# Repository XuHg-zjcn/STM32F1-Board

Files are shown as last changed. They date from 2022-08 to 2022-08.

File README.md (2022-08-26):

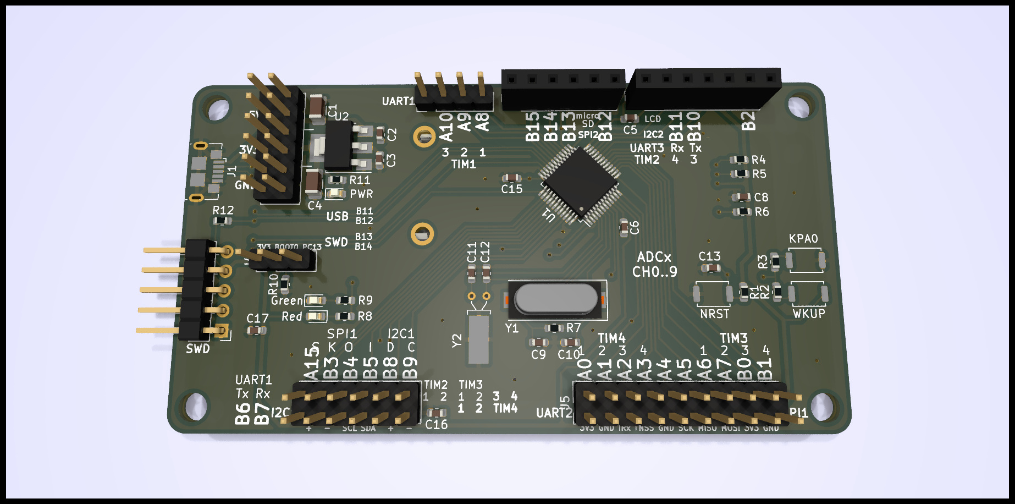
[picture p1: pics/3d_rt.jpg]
光线追踪图

# PCB描述
## 主芯片
STM32F103C8T6  LQFP48  
RAM 20kB, Flash 64kB  

## 板载元件
- 电源 : AMS1117-3.3 滤波电容47u 104
- 电池 : CR1220, 104电容
- 晶振 :  8M, 32.768K, 负载电容, 负载电阻

## 用户交互
- 按钮 : NRST, WKUP, KPA0
- LED  : 红绿双色(PC13, 一个引脚驱动两个LED)
- OLED : I2C四针插口J9

## 接口
|标识| 名称|描述 |
|:--:|:---:|:---|
| J1 |USB  |microUSB接口 |
| J2 |电源 |GND 3V3 5V 每种电压有4个针 |
| J3 |SWD  |顺序为GND SWCLK SWDIO 3V3 5V, 是为了兼容其他的板子|
| J4 |保护 |USB, SWD, BOOT0 |
| J5 |ADC  |有10个通道 |
| J6 |SPI1 |用户, 与ADC 4,5,6,7重叠 |
| J7 |UART1|用户,  并入PA8引脚 |
| J8 |I2C1 |用户 |
| J9 |I2C2 |液晶屏, 并入PB2引脚 |
|J10 |SPI2 |有保护罩, 已经连接microSD |
|J11 |SD |microSD卡槽 |

## 未来计划
配件组合:  
- 电池: CR1220 / 3.7V锂电池(二选一)
- 储存: microSD / SPI Flash(二选一), I2C EEPROM(可选)

# 本项目规范
除了引脚编号，其他单根线的标签文字统一使用0.15mm宽度，多根线统一使用0.2mm宽度文字。

电源0.29mm

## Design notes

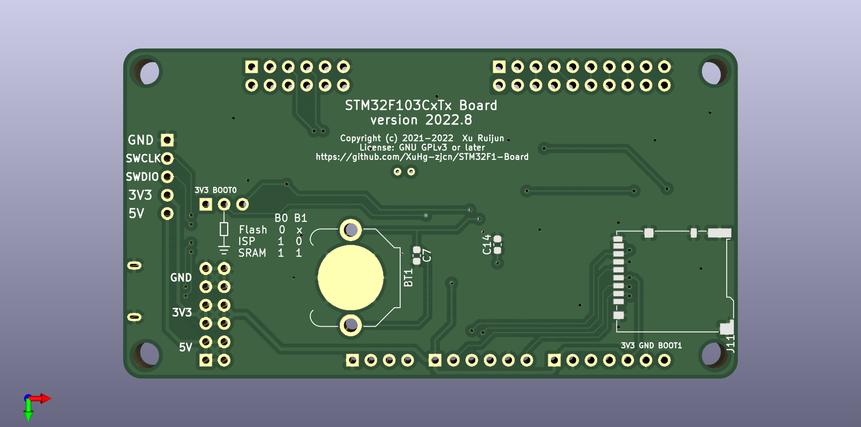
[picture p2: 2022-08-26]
pics/3d_back.png

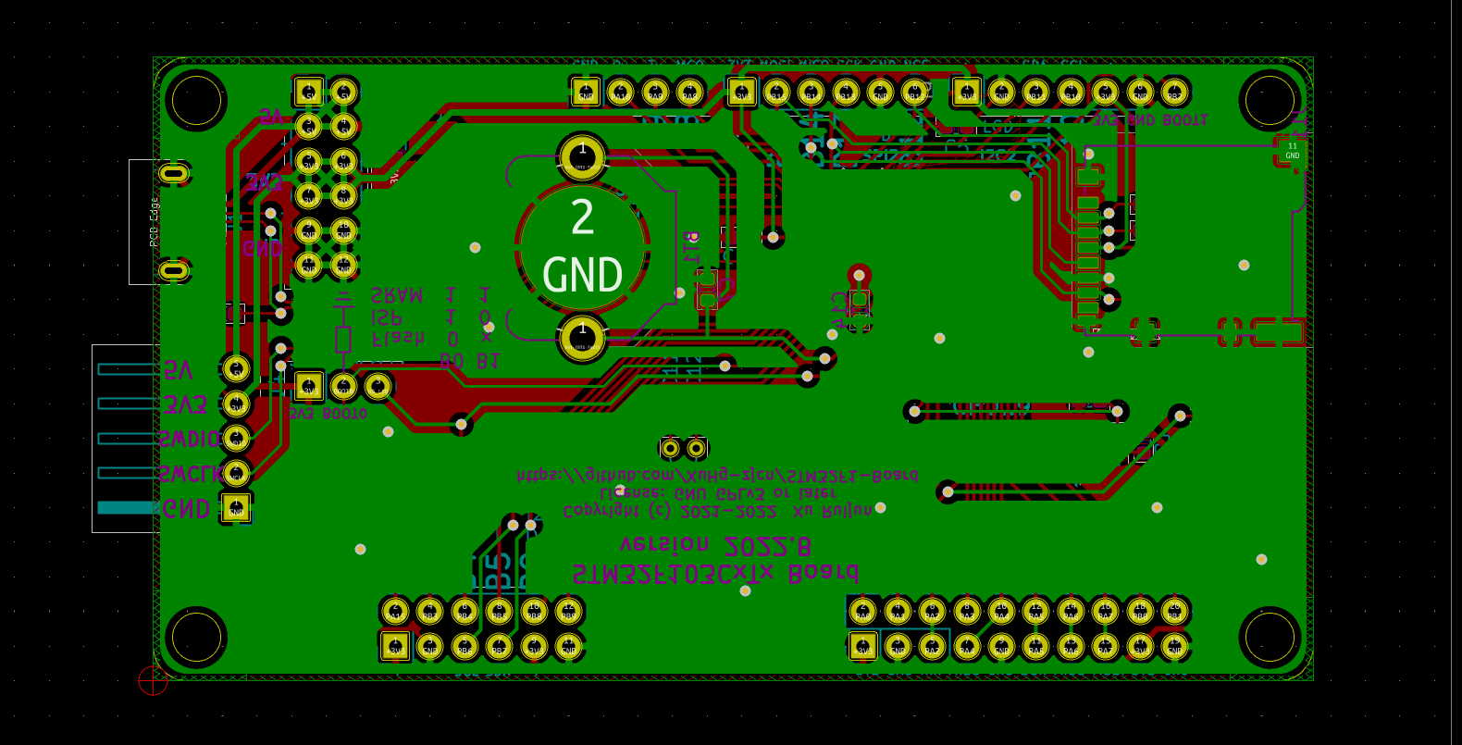
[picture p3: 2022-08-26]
pics/line_back.png

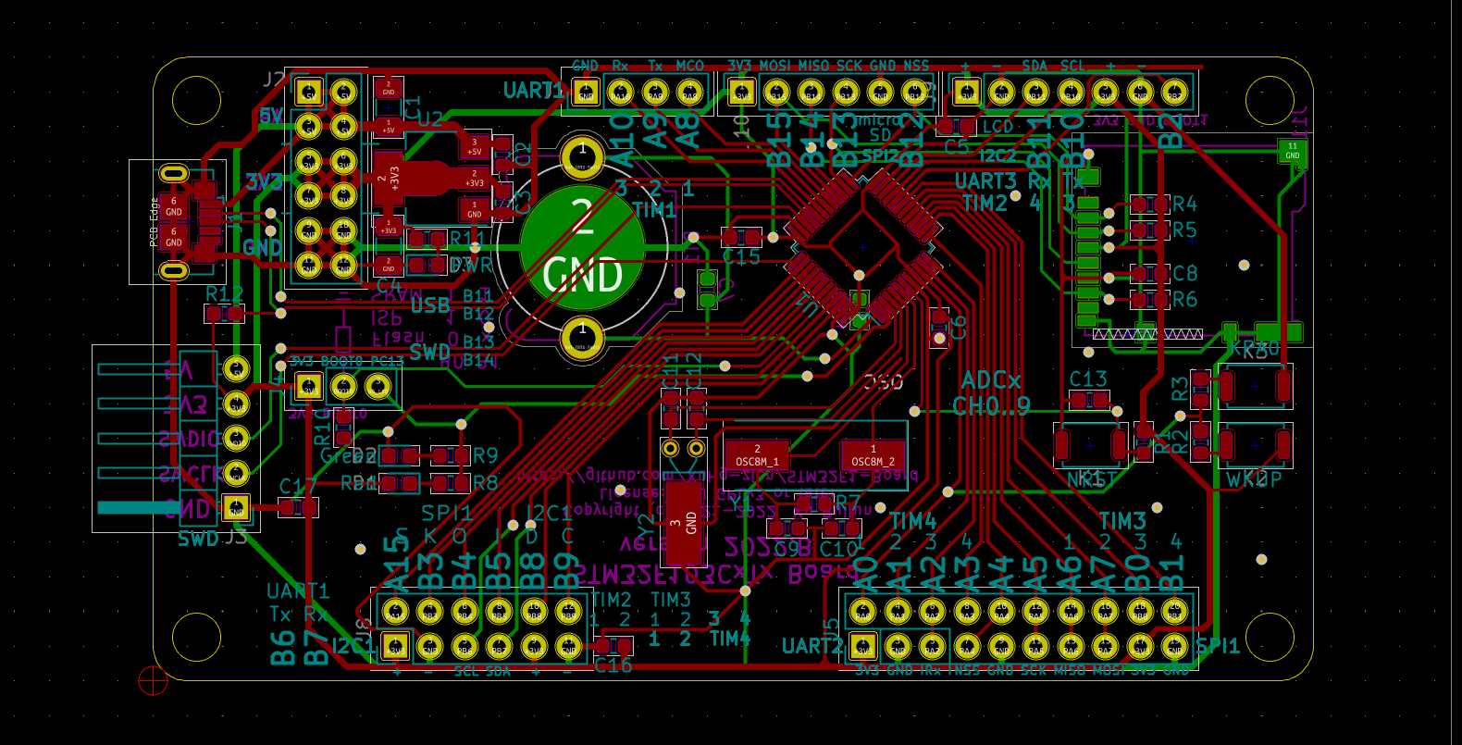
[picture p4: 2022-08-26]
pics/line_noPour.png

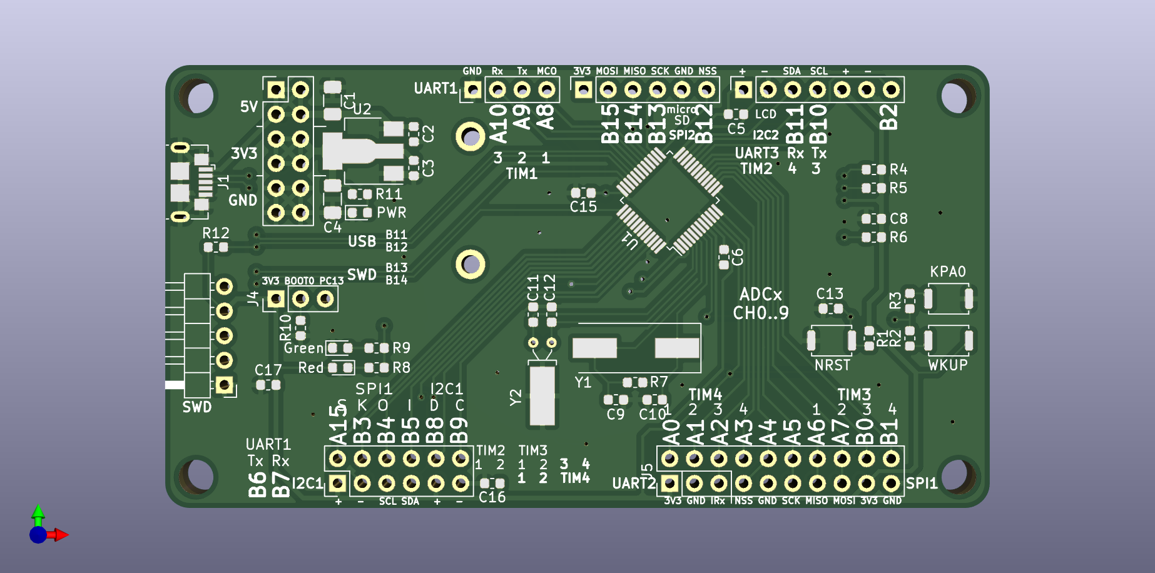
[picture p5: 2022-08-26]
pics/3d_front.png

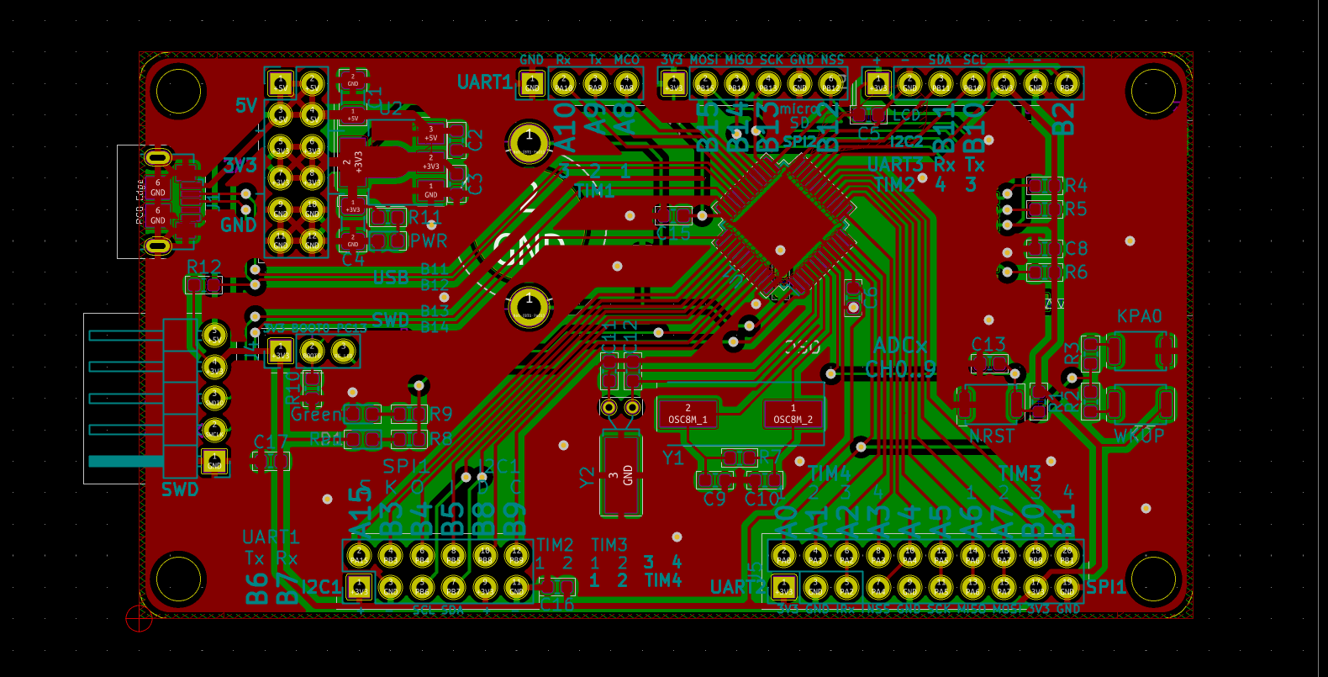
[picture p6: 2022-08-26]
pics/line_front.png

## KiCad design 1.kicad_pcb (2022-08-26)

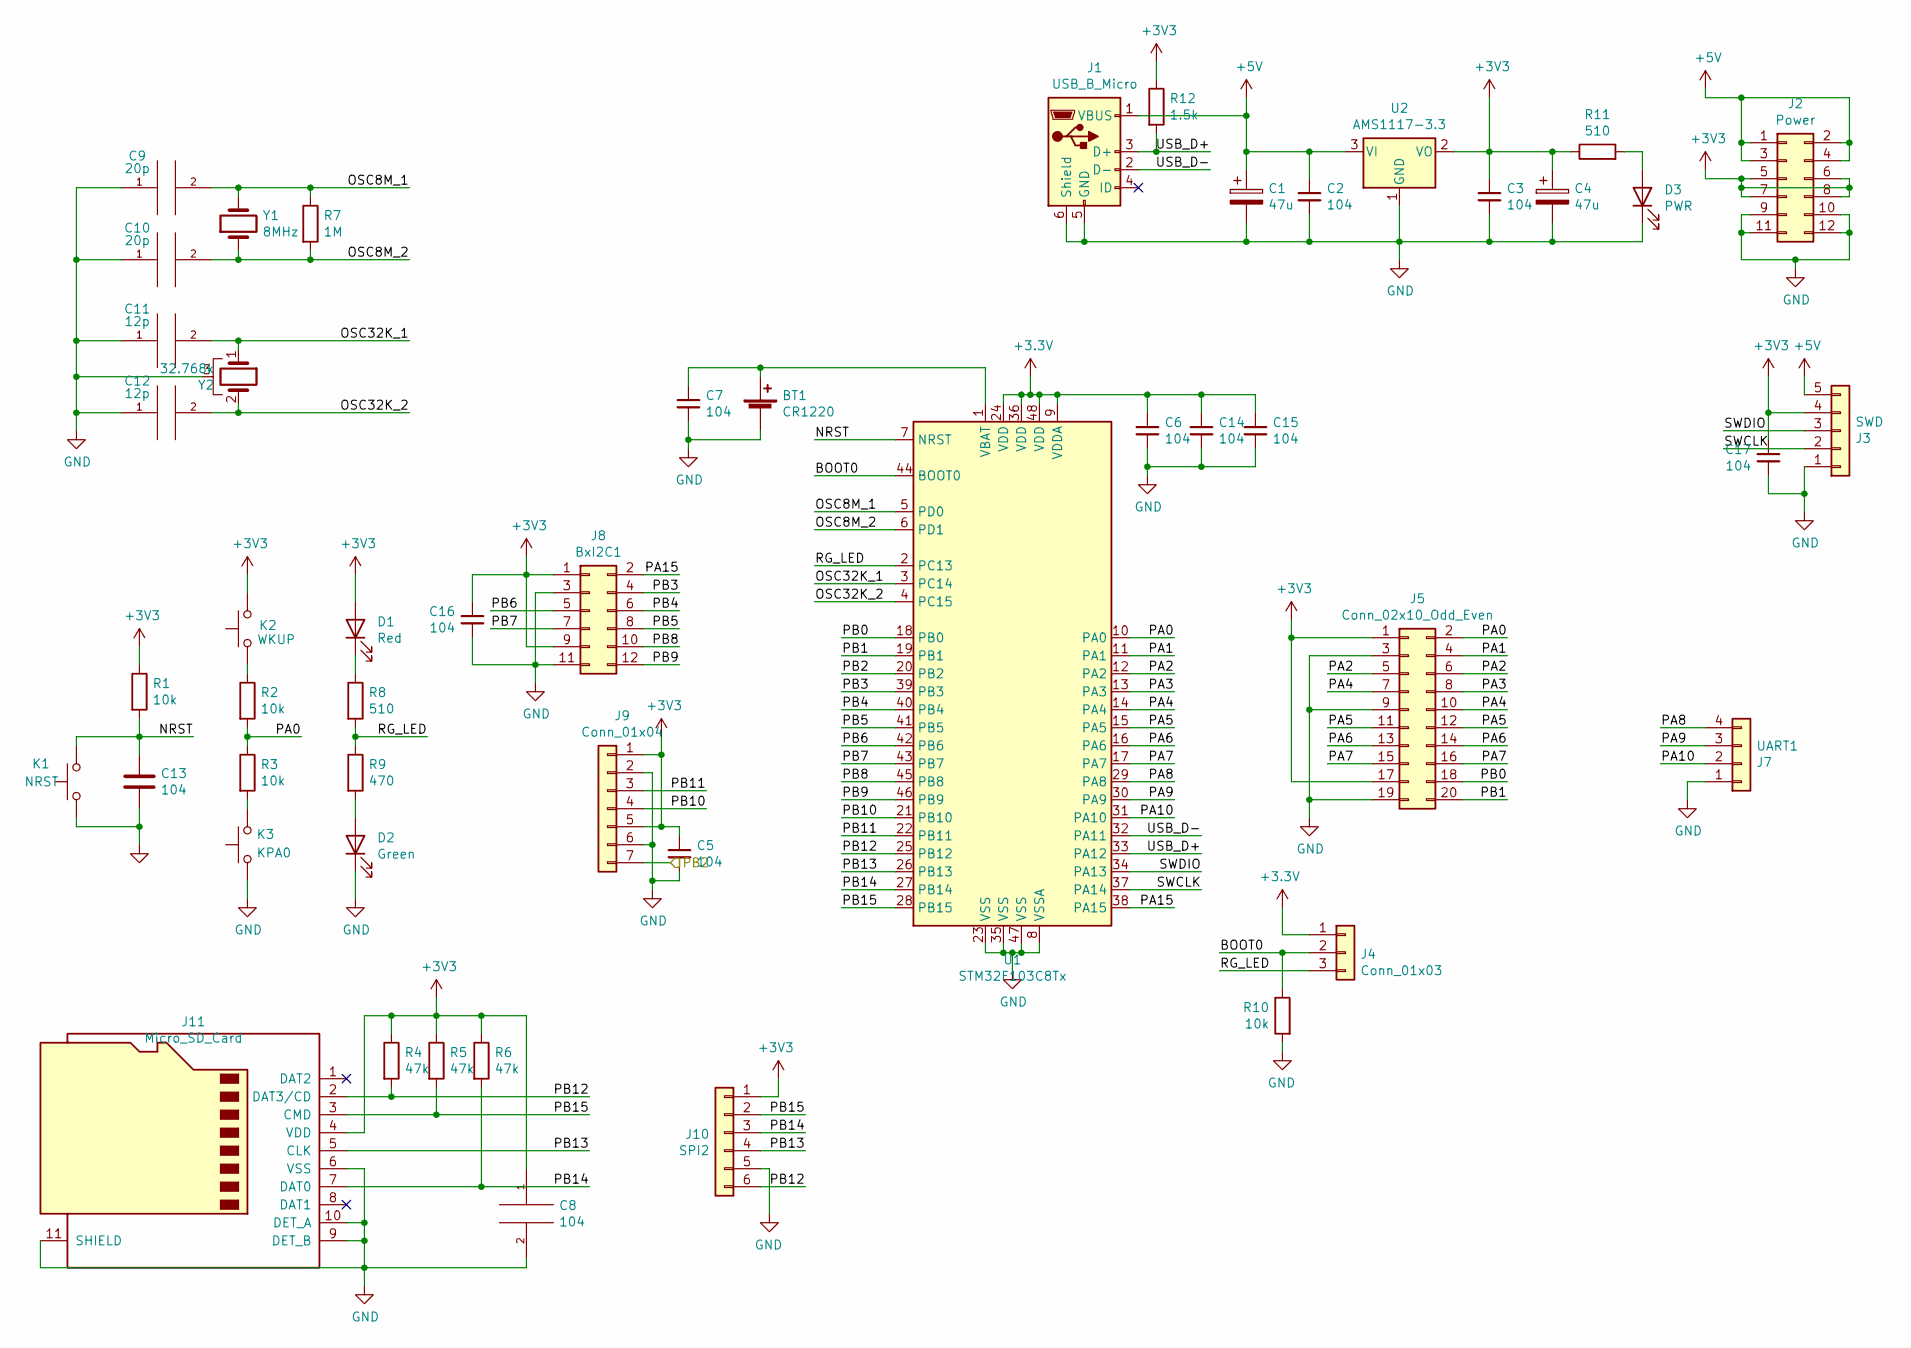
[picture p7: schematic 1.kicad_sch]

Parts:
BT1: CR1220; BatteryHolder_Keystone_3001_1x12mm
C1, C4: 47u; C_1206_3216Metric
C2, C3, C5, C6, C7, C8, C13, C14, C15, C16, C17: 104; C_0603_1608Metric
C9, C10: 20p; C_0603_1608Metric
C11, C12: 12p; C_0603_1608Metric
D1: Red; LED_0603_1608Metric
D2: Green; LED_0603_1608Metric
D3: PWR; LED_0603_1608Metric
J1: USB_B_Micro; USB_Micro-B_GCT_USB3076-30-A
J2: Power; PinHeader_2x06_P2.54mm_Vertical
J3: SWD; PinHeader_1x05_P2.54mm_Horizontal
J4: Conn_01x03; PinHeader_1x03_P2.54mm_Vertical
J5: Conn_02x10_Odd_Even; PinHeader_2x10_P2.54mm_Vertical
J7: UART1; PinHeader_1x04_P2.54mm_Vertical
J8: BxI2C1; PinHeader_2x06_P2.54mm_Vertical
J9: Conn_01x04; PinSocket_1x07_P2.54mm_Vertical
J10: SPI2; PinSocket_1x06_P2.54mm_Vertical
J11: Micro_SD_Card; microSD_HC_Hirose_DM3BT-DSF-PEJS
K1: NRST; SW_Push_SPST_NO_Alps_SKRK
K2: WKUP; SW_Push_SPST_NO_Alps_SKRK
K3: KPA0; SW_Push_SPST_NO_Alps_SKRK
R1, R2, R3, R10: 10k; R_0603_1608Metric
R4, R5, R6: 47k; R_0603_1608Metric
R7: 1M; R_0603_1608Metric
R8, R11: 510; R_0603_1608Metric
R9: 470; R_0603_1608Metric
R12: 1.5k; R_0603_1608Metric
U1: STM32F103C8Tx; LQFP-48_7x7mm_P0.5mm
U2: AMS1117-3.3; SOT-223-3_TabPin2
Y1: 8MHz; Crystal_SMD_HC49-SD
Y2: 32.768k; Crystal_DS26_D2.0mm_L6.0mm_Horizontal_1EP_style1

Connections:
+5V: C1.1, C2.1, J1.1 (VBUS), J2.1, J2.2, J2.3, J2.4, J3.5, U2.3 (VI)
/BOOT0: J4.2, R10.1, U1.44 (BOOT0)
/NRST: C13.1, K1.2, R1.2, U1.7 (NRST)
/OSC8M_1: C9.2, R7.1, U1.5 (PD0), Y1.2
/OSC8M_2: C10.2, R7.2, U1.6 (PD1), Y1.1
/OSC32K_1: C11.2, U1.3 (PC14), Y2.1
/OSC32K_2: C12.2, U1.4 (PC15), Y2.2
/PA0: J5.2, R2.2, R3.1, U1.10 (PA0)
/PA1: J5.4, U1.11 (PA1)
/PA2: J5.5, J5.6, U1.12 (PA2)
/PA3: J5.8, U1.13 (PA3)
/PA4: J5.7, J5.10, U1.14 (PA4)
/PA5: J5.11, J5.12, U1.15 (PA5)
/PA6: J5.13, J5.14, U1.16 (PA6)
/PA7: J5.15, J5.16, U1.17 (PA7)
/PA8: J7.4, U1.29 (PA8)
/PA9: J7.3, U1.30 (PA9)
/PA10: J7.2, U1.31 (PA10)
/PA15: J8.2, U1.38 (PA15)
/PB0: J5.18, U1.18 (PB0)
/PB1: J5.20, U1.19 (PB1)
/PB2: J9.7, U1.20 (PB2)
/PB3: J8.4, U1.39 (PB3)
/PB4: J8.6, U1.40 (PB4)
/PB5: J8.8, U1.41 (PB5)
/PB6: J8.5, U1.42 (PB6)
/PB7: J8.7, U1.43 (PB7)
/PB8: J8.10, U1.45 (PB8)
/PB9: J8.12, U1.46 (PB9)
/PB10: J9.4, U1.21 (PB10)
/PB11: J9.3, U1.22 (PB11)
/PB12: J10.6, J11.2 (DAT3/CD), R4.2, U1.25 (PB12)
/PB13: J10.4, J11.5 (CLK), U1.26 (PB13)
/PB14: J10.3, J11.7 (DAT0), R6.2, U1.27 (PB14)
/PB15: J10.2, J11.3 (CMD), R5.2, U1.28 (PB15)
/RG_LED: J4.3, R8.2, R9.1, U1.2 (PC13)
/SWCLK: J3.2, U1.37 (PA14)
/SWDIO: J3.3, U1.34 (PA13)
/USB_D+: J1.3 (D+), R12.2, U1.33 (PA12)
/USB_D-: J1.2 (D-), U1.32 (PA11)
GND: BT1.2 (-), C1.2, C2.2, C3.2, C4.2, C5.2, C6.2, C7.2, C8.2, C9.1, C10.1, C11.1, C12.1, C13.2, C14.2, C15.2, C16.2, C17.2, D2.1 (K), D3.1 (K), J1.5 (GND), J1.6 (Shield), J2.9, J2.10, J2.11, J2.12, J3.1, J5.3, J5.9, J5.19, J7.1, J8.3, J8.11, J9.2, J9.6, J10.5, J11.6 (VSS), J11.9 (DET_B), J11.10 (DET_A), J11.11 (SHIELD), K1.1, K3.1, R10.2, U1.8 (VSSA), U1.23 (VSS), U1.35 (VSS), U1.47 (VSS), U2.1 (GND), Y2.3
unnamed: BT1.1 (+), C7.1, U1.1 (VBAT)
unnamed: D1.1 (K), R8.1
unnamed: D2.2 (A), R9.2
unnamed: D3.2 (A), R11.2
unnamed: K2.1, R2.1
unnamed: K3.2, R3.2

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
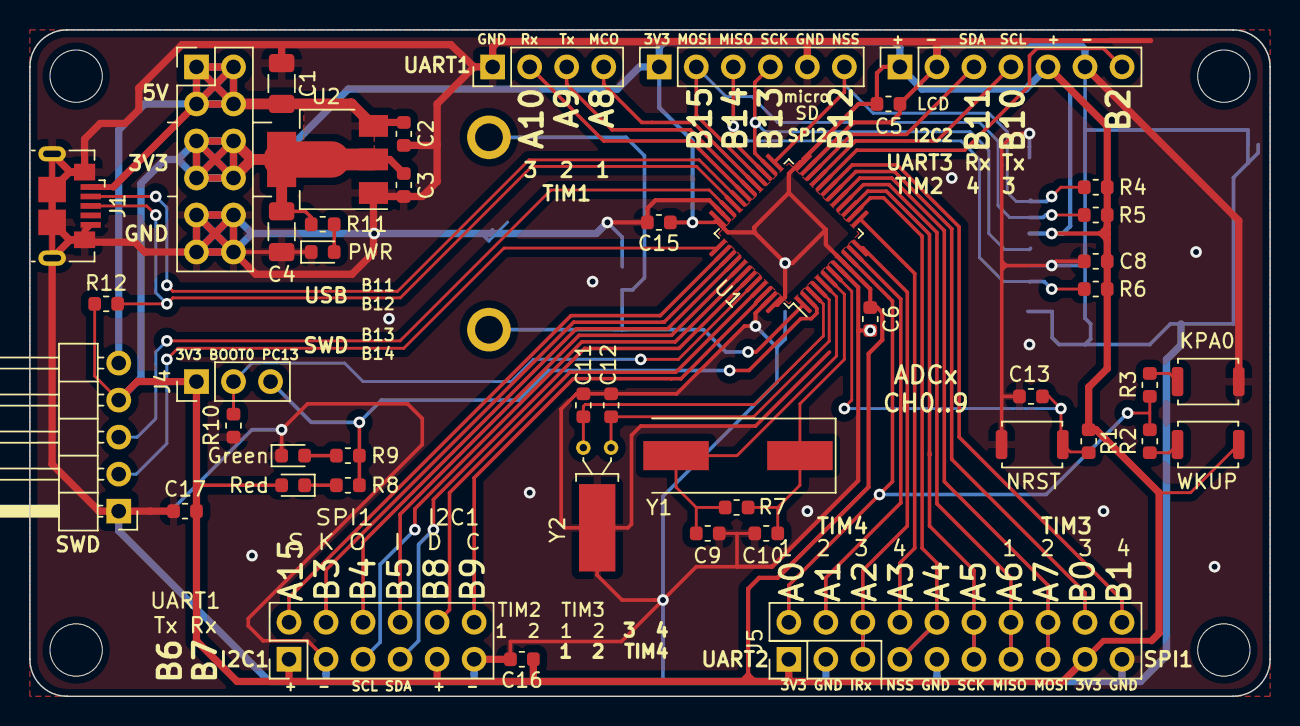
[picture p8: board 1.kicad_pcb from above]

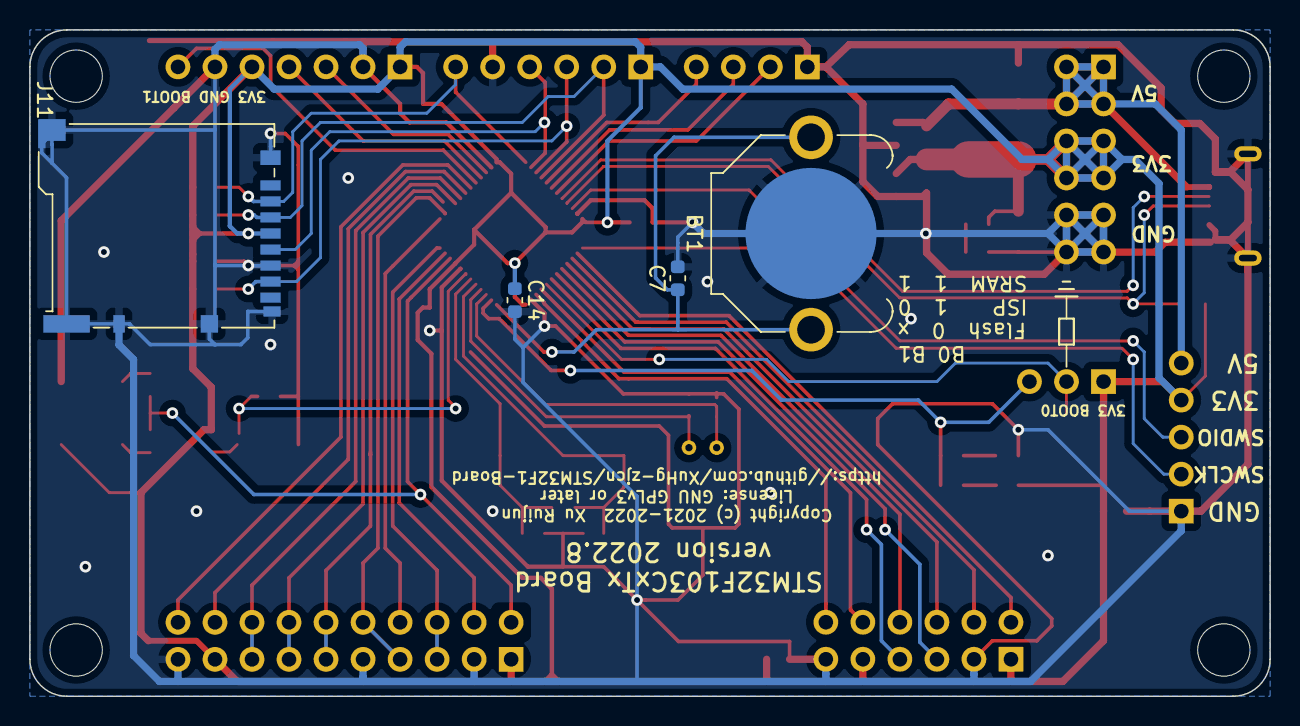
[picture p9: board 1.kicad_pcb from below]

Board: 2 copper layers, 85.1 x 45.7 mm, 50 parts (4 on the bottom side), 48 nets.

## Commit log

2021-05-02 move U1(STM32 Chip)
    [1.kicad_pcb]
2021-05-02 move edge
    [1.kicad_pcb]
2021-05-02 movdify some line
    [1.kicad_pcb]
2021-05-02 gnd line
    [1.kicad_pcb]
2021-05-02 op lines
    [1.kicad_pcb]
2021-05-02 resize edge
    [1.kicad_pcb]
2021-05-02 op gnd line
    [1.kicad_pcb]
2021-05-02 fix DRC warings
    [1.kicad_pcb]
2021-05-02 operate line near edge
    [1.kicad_pcb]
2021-05-02 fix: ADC channel no connect
    [1.kicad_pcb]
2021-05-02 label two colors
    [1.kicad_pcb]
2021-05-03 SD ground
    [1.kicad_pcb, 1.sch]
2021-05-03 fix lines
    [1.kicad_pcb]
2021-05-03 fix lines2
    [1.kicad_pcb]
2021-05-04 fix: 32.768k OSC pin
    [1.kicad_pcb, 1.sch]
2021-05-04 fix: power line
    [1.kicad_pcb]
2021-05-04 add 104 caps
    [1.kicad_pcb, 1.sch]
2021-05-04 use 2x6 header for BxI2C1
    [1.kicad_pcb, 1.sch]
2021-05-04 I2C1 line
    [1.kicad_pcb]
2021-05-04 5V line on 1206 cap
    [1.kicad_pcb]
2021-05-04 GND line under battary
    [1.kicad_pcb]
2021-05-04 fix: edge
    [1.kicad_pcb]
2021-05-04 fix: usb GND对称性
    [1.kicad_pcb]
2021-05-04 fix: GND line on VSSA cap
    [1.kicad_pcb]
2021-05-04 fix: 3.3V line near edge
    [1.kicad_pcb]
2021-05-04 fill area
    [1.kicad_pcb]
2021-05-04 silks layer
    [1.kicad_pcb]
2021-05-04 move pin headers on 原理图
    [1.sch]
2021-05-04 rename label to PAxx/PBxx on 原理图
    [1.sch]
2021-05-04 添加不连接标签
    [1.sch]
2021-05-04 使用网络标签代替层次标签
    [1.kicad_pcb, 1.sch]
2021-05-04 移动PCB标签
    [1.kicad_pcb]
2021-05-04 修改原理图字段，并修改PCB
    [1.kicad_pcb, 1.sch]
2021-05-04 修改字段2
    [1.sch]
2021-05-04 填充GND
    [1.kicad_pcb]
2021-05-04 修复靠近边缘的线突出
    [1.kicad_pcb]
2021-05-04 BOOT0标签
    [1.kicad_pcb]
2021-05-04 压缩按钮空间
    [1.kicad_pcb]
2021-05-04 SD卡槽连接
    [1.kicad_pcb]
2021-05-04 move C11,C12 label
    [1.kicad_pcb]
2021-05-05 移除无用的过孔
    [1.kicad_pcb]
2021-05-05 label of SWD port
    [1.kicad_pcb]
2021-05-05 usb port lines
    [1.kicad_pcb]
2021-05-05 move usb
    [1.kicad_pcb]
2021-05-05 usb port GND line
    [1.kicad_pcb]
2021-05-05 lines op2
    [1.kicad_pcb]
2021-05-05 SWD,3V3 lines
    [1.kicad_pcb]
2021-05-05 fill GND
    [1.kicad_pcb]
2021-05-05 move label B6,B7
    [1.kicad_pcb]
2021-05-05 move label of PinHeaders
    [1.kicad_pcb]
2021-05-05 line of PA4
    [1.kicad_pcb]
2021-05-05 fix GND near to fill
    [1.kicad_pcb]
2021-05-05 add label "STM32F103C8T6 Board, by XuRuijun, QQ 1687701765"
    [1.kicad_pcb]
2021-05-06 USB GND线
    [1.kicad_pcb]
2021-05-06 MCU pin 36 connect to 3.3V
    [1.kicad_pcb]
2021-05-06 move 32.768k OSC
    [1.kicad_pcb, 1.sch]
2021-05-06 op power lines
    [1.kicad_pcb]
2021-05-06 op power lines2
    [1.kicad_pcb]
2021-05-06 op power lines3
    [1.kicad_pcb]
2021-05-06 bat line
    [1.kicad_pcb]
2021-05-06 op power line4
    [1.kicad_pcb]
2021-05-06 op power line5
    [1.kicad_pcb]
2021-05-06 op lines 6
    [1.kicad_pcb]
2021-05-06 op GND line near USB
    [1.kicad_pcb]
2021-05-06 USB信号线过孔附件倒角
    [1.kicad_pcb]
2021-05-06 J4 USB信号线离焊盘太近
    [1.kicad_pcb]
2021-05-06 边缘GND线
    [1.kicad_pcb]
2021-05-06 晶振线路
    [1.kicad_pcb]
2021-05-06 调整晶振位置
    [1.kicad_pcb]
2021-05-06 晶振使用0.2mm线
    [1.kicad_pcb]
2021-05-06 晶振使用0.2mm线-2
    [1.kicad_pcb]
2021-05-07 MCU左上角三个通孔
    [1.kicad_pcb]
2021-05-07 填充GN
    [1.kicad_pcb]
2021-05-07 move labels
    [1.kicad_pcb]
2021-05-07 GND line near microSD card
    [1.kicad_pcb]
2021-05-07 add PinSocket
    [1.kicad_pcb, 1.sch]
2021-05-07 coner hole, 3.3V line near microSD card
    [1.kicad_pcb]
2021-05-07 save .sch file
    [1.sch]
2021-05-07 op in windows
    [1.kicad_pcb, 1.sch]
2021-05-08 重新布线，取消SWD和USB排针
    [1.kicad_pcb, 1.sch]
2021-05-08 move usb and swd line insert gnd between
    [1.kicad_pcb]
2021-05-08 fill and via
    [1.kicad_pcb]
2021-05-08 move via
    [1.kicad_pcb]
2021-05-08 op via holes
    [1.kicad_pcb]
2021-05-08 op via holes2
    [1.kicad_pcb]
2021-05-08 op via holes3
    [1.kicad_pcb]
2021-05-08 USB D+ 1.5k up res, 104 cap near SWD
    [1.kicad_pcb, 1.sch]
2021-05-08 op power lines 0.29mm
    [1.kicad_pcb]
2021-05-08 relink GND line near 32.768k OSC
    [1.kicad_pcb]
2021-05-08 添加禁布区，清除104电容的覆盖铜
    [1.kicad_pcb]
2021-05-08 视频中修改
    [1.kicad_pcb]
2021-05-08 tran 90deg
    [1.kicad_pcb]
2021-05-08 lines near power PinHeader
    [1.kicad_pcb]
2021-05-08 line wider to 0.5mm, move micro sd lines
    [1.kicad_pcb]
2021-05-08 优化microSD走线，加了两个过孔
    [1.kicad_pcb]
2021-05-08 优化microSD走线，3.3V电源线
    [1.kicad_pcb]
2021-05-08 移动板子与50mil网格重合
    [1.kicad_pcb]
2021-05-09 PC13 replace I2C1 one of 3V3
    [1.kicad_pcb, 1.sch]
2021-05-15 copy from windows, 成功打样
    [1.kicad_pcb, 1.sch]
2021-06-30 2x10 pins
    [1.kicad_pcb, 1.sch]
2021-06-30 add line on silks layer
    [1.kicad_pcb]
2021-06-30 conver Cu
    [1.kicad_pcb]
2021-06-30 save 1.sch
    [1.sch]
2022-08-25 提交遗留内容
2022-08-25 fix: 把J5放置在正面
    [1.kicad_pcb]
2022-08-25 update to KiCad 6
    [1.kicad_sch, 1.sch]
2022-08-26 添加GPLv3许可证并应用，GitHub仓库网址，移除"JLCJLCJLCJLC"
    [1.kicad_pcb]
2022-08-26 "文档"和"规范.txt"合并为"README.md"
2022-08-26 提交图片并插入README.md

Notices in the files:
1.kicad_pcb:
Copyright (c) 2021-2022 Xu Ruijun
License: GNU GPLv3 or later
